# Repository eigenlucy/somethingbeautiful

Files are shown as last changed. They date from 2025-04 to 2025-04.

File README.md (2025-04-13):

# PATHFINDER

A route and activity planning bot that lives in a panel beside your door, built for the Something Beautiful Hackathon.

## Team

* [Lucy Moglia](https://eigenlucy.github.io): PCB Design, Firmware Design, Atopile Integration
* [Veronica Chambers](https://www.linkedin.com/in/victoria-cabrera-moglia/): Backend Design, LLM Integration, LLM Persistence and Memory System
* [Jessie Stiles](https://jessiestiles.github.io/portfolio1.github.io/): Enclosure CAD Design
* [Yoyo](https://exanova-y.github.io): UX Design, Pathfinding, Route Visualization

## Overview

PATHFINDER is an intelligent route planning device that helps you explore your surroundings. Tell it where you want to go, how much of a rush you're in, and what kind of activities you're looking for, and it will plan your perfect route by analyzing various databases. The system features personality-driven agents that adapt to each user's preferences over time.

### Hardware

- ESP32-S3 microcontroller
- MAX98357 I2S digital amplifier (esp-hal i2s audio library)
- ST7735S based 128 × 160 pixel LCD (st7735-lcd crate)
- WS2812B Neopixels (smart_leds crate)
- Custom PCB design (can be ordered pre-assembled)

## Atopile Hardware Architecture

The hardware is designed using [atopile](https://docs.atopile.io/latest/), a modern hardware description language that generates PCB designs. The system architecture is structured as follows:

### Components Diagram

```
┌───────────────────────────┐
│       Veramonitor         │
└───────────┬───────────────┘
            │
            ├── Power Management
            │   ├── USB-C Connector (5V)
            │   └── AMS1117-33 LDO (3.3V)
            │
            ├── Processing
            │   └── ESP32-S3 Microcontroller
            │
            ├── Input/Output
            │   ├── 6× Kailh Mechanical Switches (with RGB LEDs)
            │   ├── 1.8" TFT LCD Display (ST7735S)
            │   ├── Digital Amplifier (MAX98357) + Speaker
            │   └── MEMS Microphone (SPH0641LU4H-1)
            │
            └── Interfaces
                ├── I2C (Qwiic connector)
                ├── SPI (for LCD)
                ├── I2S (for audio)
                ├── JTAG (programming header)
                └── USB2 (for communication)
```

### Connection Diagram

The main components are connected as follows:

```
┌─────────────┐     Power (5V)     ┌────────────┐
│  USB-C Port ├───────────────────►│  AMS1117   │
└─────────────┘                    └─────┬──────┘
                                         │
                                         │ Power (3.3V)
                                         ▼
┌─────────────┐     I2C, SPI     ┌──────────────┐     GPIO     ┌─────────────┐
│  Qwiic I2C  │◄────────────────►│   ESP32-S3   ├────────────►│ Kailh Keys  │
└─────────────┘                  │              │              │ with SK6805 │
                                 │              │              │    LEDs     │
┌─────────────┐     SPI          │              │              └─────────────┘
│  1.8" LCD   │◄────────────────►│              │
└─────────────┘                  │              │
                                 │              │    I2S       ┌─────────────┐
┌─────────────┐     PDM          │              ├────────────►│   MAX98357  │
│ MEMS Mic    ├────────────────►│              │              │     Amp     │
└─────────────┘                  └──────────────┘              └──────┬──────┘
                                                                      │
                                                                      ▼
                                                               ┌─────────────┐
                                                               │   Speaker   │
                                                               └─────────────┘
```

The design files are built with atopile and can be found in `ESPHome-Panel/elec/src/`.

## Getting Started

### Prerequisites

- [atopile](https://docs.atopile.io/latest/) - For PCB design
- [rust](https://rustup.rs/), [espup](https://docs.esp-rs.org/book/installation/riscv-and-xtensa.html), [espflash](https://github.com/esp-rs/espflash) - For firmware development

See [ATO_USAGE.md](ATO_USAGE.md) for detailed instructions on working with atopile.

### Building the PCB

1. Clone the repository with submodules:
   ```
   git submodule update --init --recursive
   ```

2. Build the project:
   ```
   ato build -t all
   ```

3. Review the layout in KiCad PCB editor

4. Gerbers and PCBA files are generated through Actions runs

## References/Dependencies

* [OpenRouteService](https://openrouteservice.org/)
* [OpenRouteService Route Visualization Guide](https://medium.com/@atulvpoddar4/visualizing-routes-with-real-data-a-python-guide-to-interactive-mapping-db14189cf185)
* [Izzymonitor Project Page](https://eigenlucy.github.io/projects/izzymonitor/) and [Repo with pin refs](https://github.com/eigenlucy/ESPHome-Panel/tree/izzymonitor/)
* [Izzymonitor actions run associated with PCB on hand](https://github.com/eigenlucy/ESPHome-Panel/actions/runs/13046416119)

## Project Structure

| Directory | Description |
|---|---|
| `/` | Root directory with main README and documentation |
| `/3DModels/` | 3D model files for the enclosure (STEP files) |
| `/ESPHome-Panel/` | Hardware design files using atopile |
| `/ESPHome-Panel/elec/` | Electronic design files |
| `/ESPHome-Panel/elec/src/` | Source files for the PCB design |
| `/ESPHome-Panel/elec/layout/` | KiCad PCB layout files |
| `/ESPHome-Panel/elec/footprints/` | Custom footprints for components |
| `/ESPHome-Panel/build/` | Build outputs including BOM, gerbers, etc. |
| `/RustFirmwareWorking/` | Firmware source code in Rust |
| `/RustFirmwareWorking/izzymonitor-firmware/` | Current firmware implementation |
| `/RustFirmwareWorking/izzymonitor-firmware/src/` | Rust source code for firmware |
| `/RustFirmwareWorking/izzymonitor-firmwareWorkingBak/` | Backup of working firmware |

## Project Status and To-Do List

### PCB/Basic Firmware
- [x] PCB works
- [x] Initial atopile setup
- [x] Get Ato build working with V3 compiler
- [ ] Board recording sound from PDM I2S microphone
- [ ] ST7735 LCD display working over SPI
- [ ] I2S amp/speaker working 
- [x] Buttons/WS2812B LEDs working

### Enclosure
- [x] Design 3D-printable wall-mountable enclosure with personality
- [x] Accommodate all components (buttons, microphone, speakers, USB ports)

### Firmware/UI
- [ ] UI/Menu design
- [ ] LCD text based UI and voice animations
- [ ] Web server integration to send and receive audio and text
- [ ] Button-based UI for user selection, mode settings, and volume control
- [ ] Route feedback convo mode

### LLM Integration
- [ ] User recognition with personalized agents
- [x] Route planning integration (OpenRouteService)
- [ ] Voice synthesis and speech recognition
- [x] Agent personality development
- [ ] Gradual Infilatration of Fixations to Pathfinding :3

### Backend
- [ ] Request processing from device
- [x] Speech-to-text integration
- [ ] Audio and text file sharing from web server
- [x] Agent persistence and memory system for user preferences
- [x] Map / location lookup system

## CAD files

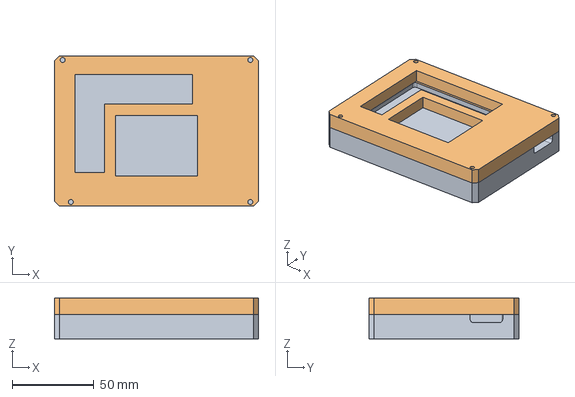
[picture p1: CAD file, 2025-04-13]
3DModels/HAassembly.step
125.0 x 92.0 x 25.0 mm
lid

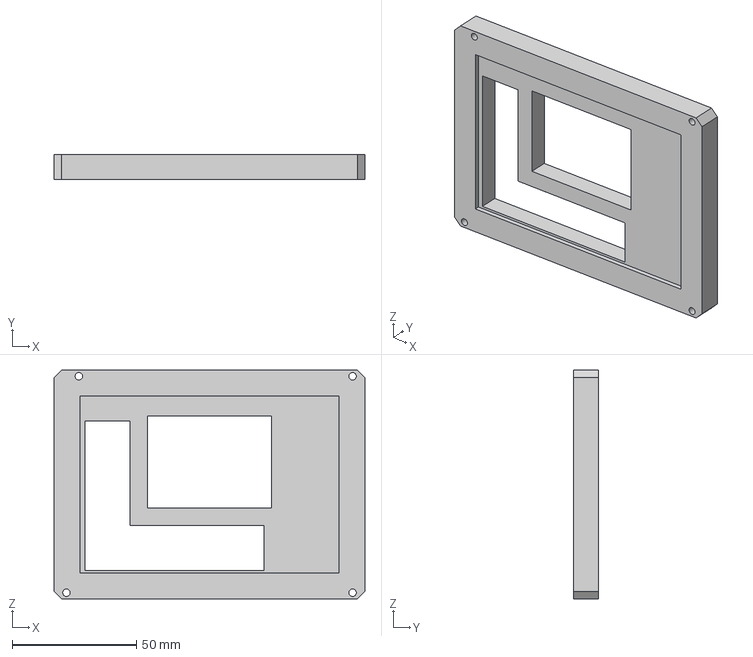
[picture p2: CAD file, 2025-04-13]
3DModels/lid v4.step
125.0 x 10.0 x 92.0 mm

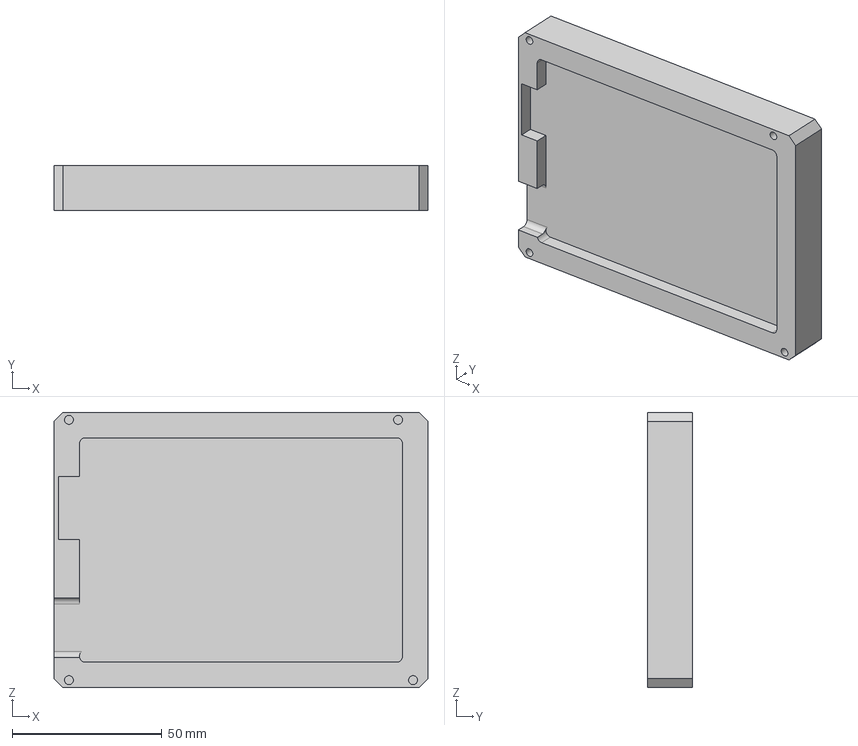
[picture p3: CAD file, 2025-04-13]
3DModels/HAbase.step
125.0 x 15.0 x 92.0 mm

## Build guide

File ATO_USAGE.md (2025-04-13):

# Atopile Usage 101
See [atopile docs](https://docs.atopile.io/atopile/introduction) for detailed guides on usage. Install instructions below

## Building the project
### 1: Clone the required submodules
```$ git submodule update --init --recursive```
- You actually wanna make sure you are using the specific commit hash we built this around for the ESPHome-Panel
### 2: Build the project to select components based on JLCPCB availability and load them into the kicad PCB
``` $ ato build -t all```
### 3: Complete/review the layout with Kicad Standalone PCB editor
### 4: Gerbers/PCBA files are generated through an Actions run on a commit and placed in the build artifacts folder

## Linux Install (should work with Ubuntu, Debian, Arch, and NixOS)
### 1: Install [uv](https://github.com/astral-sh/uv)
### 2: Install kicad with your preferred package manager (apt for debian, pacman for arch, etc)
### 3: Install atopile as a tool with uv. As of writing this, you should be using python 3.13.2 
```$ uv tool install atopile```
#### 3.1: (alternative install, my preferred method, easier to debug and manage versions):
#### 3.2: clone the main [atopile repo](https://github.com/atopile/atopile)
#### 3.3: remove the uv lock file
```$ rm uv.lock```
#### 3.4: sync repo to dev release
```$ uv sync --dev```
#### 3.5: compile atopile
```$ uv build```
#### 3.6: install the binary
```$ uv tool install atopile-0.3.XX-cp313-cp313-linux-_x86_64.whl```
#### 3.7: Add the uv tools binary directory to your PATH (command depends on your shell, eg with fish)
```$ fish_add_path /home/user/.local/share/uv/tools/atopile/```
### 4: Check your version with 
```$ ato --version```
### 5: configure the atopile plugin 
```$ ato configure```

## Mac Install
### 1: Install [Homebrew](https://brew.sh/)
### 2: Install [kicad 9](https://formulae.brew.sh/cask/kicad)
### 3: install atopile with Homebrew 
```$ brew install atopile/tap/atopile```
### 4: configure the atopile plugin 
```$ ato configure```

## Visual Studio Code/Cursor Extension Install
Install the [atopile extension](https://marketplace.visualstudio.com/items?itemName=atopile.atopile) into Cursor or VSC

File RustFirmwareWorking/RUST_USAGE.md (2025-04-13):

# Refs/Deps:
- Install the Rust toolchain with [RustUp](https://rustup.rs/)
- Install [espup](https://docs.esp-rs.org/book/installation/riscv-and-xtensa.html)
- Install [espflash](https://docs.esp-rs.org/book/tooling/espflash.html)
- [Rust On ESP-IDF Template](https://github.com/esp-rs/esp-idf-template)

# Libraries:
- [LCD Library](https://crates.io/crates/st7735-lcd), see [Repo](https://github.com/sajattack/st7735-lcd-rs) with docs
- [SmartLeds](https://docs.rs/smart-leds/latest/smart_leds/), for the neopixels
- [ESP32 I2S Audio Library](https://docs.rs/esp32-hal/latest/esp32_hal/i2s/index.html), handles the audio from the microphone and to the speaker

# Flashing
- Install prereqs ```$ cargo generate esp-rs/esp-idf-template cargo```
- ```$ cargo build```
- ```$ cargo run --release```

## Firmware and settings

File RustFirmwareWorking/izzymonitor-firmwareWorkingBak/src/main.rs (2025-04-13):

//! Main entry point for VeraMonitor
//! ESP32-S3 based wall-mounted LLM-integrated Google Maps assistant

#![no_std]
#![no_main]
#![feature(type_alias_impl_trait)]

use esp_backtrace as _;
use esp_hal::{
    clock::{ClockControl, CpuClock},
    gpio::{AnyPin, Gpio0, Gpio10, Gpio11, Gpio12, Gpio13, Gpio14, Gpio16, Gpio21, Gpio35, Gpio45, Gpio46, Gpio47, Gpio48, Gpio9, GpioPin, Input, Output, PullUp, PushPull},
    prelude::*,
    rmt::{PulseCode, Rmt, TxChannel, TxChannelConfig},
    peripherals::Peripherals,
    spi::master::{Spi, SpiBus},
    timer::TimerGroup,
    IO,
};
use embassy_executor::Spawner;
use embassy_time::{Duration, Timer};
use esp_println::println;
use heapless::Vec;

mod display;
mod buttons;
mod led;

use display::ButtonLayout;
use buttons::{Button, BUTTON_STATES};
use led::{LedController, colors, RgbColor};

// Number of LEDs in the strip
const LED_COUNT: usize = 6;

// RMT buffer size (each LED needs 24 bits × 2 pulses per bit + reset pulse)
const RMT_BUFFER_SIZE: usize = LED_COUNT * 24 * 2 + 1;

// Define the menu system
enum MenuScreen {
    Startup,
    Main,
    Trip,
    Settings,
}

// Define button labels for different screens
const MAIN_BUTTONS: [&str; 6] = ["Menu", "Trip", "Set", "Mic", "Up", "Down"];
const TRIP_BUTTONS: [&str; 6] = ["Back", "New", "View", "Map", "Up", "Down"];
const SETTINGS_BUTTONS: [&str; 6] = ["Back", "WiFi", "LED", "User", "Up", "Down"];

// Task for display management
#[embassy_executor::task]
async fn display_task(
    mut lcd: display::Display,
    active_button: &'static core::cell::Cell<usize>,
) {
    // Start with the startup screen
    let mut current_screen = MenuScreen::Startup;
    lcd.draw_startup().unwrap();
    
    // Wait a moment on the startup screen
    Timer::after(Duration::from_millis(2000)).await;
    
    // Switch to main screen
    current_screen = MenuScreen::Main;
    let mut layout = ButtonLayout {
        labels: MAIN_BUTTONS,
        active_index: 0,
    };
    
    lcd.draw_main_screen(&layout).unwrap();
    
    loop {
        // Get the currently active button
        let current_button = active_button.get();
        
        // Update the active button in the layout if it changed
        if current_button != layout.active_index {
            layout.active_index = current_button;
            
            // Redraw based on current screen
            match current_screen {
                MenuScreen::Startup => {
                    // Shouldn't get here, but just in case
                    lcd.draw_startup().unwrap();
                },
                MenuScreen::Main => {
                    layout.labels = MAIN_BUTTONS;
                    lcd.draw_main_screen(&layout).unwrap();
                },
                MenuScreen::Trip => {
                    layout.labels = TRIP_BUTTONS;
                    lcd.draw_title("Trip Planner").unwrap();
                    lcd.draw_buttons(&layout).unwrap();
                },
                MenuScreen::Settings => {
                    layout.labels = SETTINGS_BUTTONS;
                    lcd.draw_title("Settings").unwrap();
                    lcd.draw_buttons(&layout).unwrap();
                },
            }
        }
        
        // Check for screen transitions based on button presses
        for (i, state) in BUTTON_STATES.iter().enumerate() {
            let button_state = critical_section::with(state, |s| {
                *s.borrow()
            });
            
            if button_state == buttons::ButtonState::Pressed {
                match (current_screen, i) {
                    // From main screen
                    (MenuScreen::Main, 0) => {}, // Menu button does nothing on main screen
                    (MenuScreen::Main, 1) => {
                        // Trip button - go to trip screen
                        current_screen = MenuScreen::Trip;
                        layout.labels = TRIP_BUTTONS;
                        layout.active_index = 0;
                        lcd.clear().unwrap();
                        lcd.draw_title("Trip Planner").unwrap();
                        lcd.draw_box(5, 25, display::SCREEN_WIDTH - 10, display::SCREEN_HEIGHT - 60).unwrap();
                        lcd.draw_text("No trips scheduled", 20, 50, display::COLOR_TEXT, false).unwrap();
                        lcd.draw_buttons(&layout).unwrap();
                    },
                    (MenuScreen::Main, 2) => {
                        // Settings button - go to settings screen
                        current_screen = MenuScreen::Settings;
                        layout.labels = SETTINGS_BUTTONS;
                        layout.active_index = 0;
                        lcd.clear().unwrap();
                        lcd.draw_title("Settings").unwrap();
                        lcd.draw_box(5, 25, display::SCREEN_WIDTH - 10, display::SCREEN_HEIGHT - 60).unwrap();
                        lcd.draw_text("WiFi: Not Connected", 10, 40, display::COLOR_TEXT, false).unwrap();
                        lcd.draw_text("LED: Medium", 10, 55, display::COLOR_TEXT, false).unwrap();
                        lcd.draw_text("User: Guest", 10, 70, display::COLOR_TEXT, false).unwrap();
                        lcd.draw_buttons(&layout).unwrap();
                    },
                    
                    // From trip screen
                    (MenuScreen::Trip, 0) => {
                        // Back button - go to main screen
                        current_screen = MenuScreen::Main;
                        layout.labels = MAIN_BUTTONS;
                        layout.active_index = 0;
                        lcd.draw_main_screen(&layout).unwrap();
                    },
                    
                    // From settings screen
                    (MenuScreen::Settings, 0) => {
                        // Back button - go to main screen
                        current_screen = MenuScreen::Main;
                        layout.labels = MAIN_BUTTONS;
                        layout.active_index = 0;
                        lcd.draw_main_screen(&layout).unwrap();
                    },
                    
                    // Default - ignore other button presses
                    _ => {},
                }
                
                // Break after handling a button press
                break;
            }
        }
        
        // Short delay to prevent excessive CPU usage
        Timer::after(Duration::from_millis(50)).await;
    }
}

// Main function
#[embassy_executor::main]
async fn main(spawner: Spawner) {
    // Initialize the ESP32
    println!("Starting VeraMonitor...");
    let peripherals = Peripherals::take();
    
    // Configure clocks
    let system = peripherals.SYSTEM.split();
    let clocks = ClockControl::configure(system.clock_control, CpuClock::Clock240MHz).freeze();
    
    // Configure I/O
    let io = IO::new(peripherals.GPIO, peripherals.IO_MUX);
    
    // Initialize the timer
    let timer_group0 = TimerGroup::new(peripherals.TIMG0, &clocks);
    embassy_time::time_driver_embassy_time_timg0::schedule_timer(timer_group0);
    
    // Configure LED backlight for display
    let mut backlight = io.pins.gpio46.into_push_pull_output();
    backlight.set_high().unwrap();
    
    // Configure the SPI interface for the display
    let spi = peripherals.SPI2;
    let sclk = io.pins.gpio12;
    let mosi = io.pins.gpio13;
    let cs = io.pins.gpio11;
    
    // Configure DC and RST pins
    let dc = io.pins.gpio10.into_push_pull_output();
    let rst = io.pins.gpio9.into_push_pull_output();
    
    // Configure SPI
    let spi_config = esp_hal::spi::master::Config::new()
        .baudrate(27.MHz().into())
        .bit_order(esp_hal::spi::master::BitOrder::MsbFirst)
        .data_mode(esp_hal::spi::master::Mode::Mode0);
    
    let spi = Spi::new(
        spi,
        sclk,
        mosi,
        Option::<esp_hal::gpio::AnyPin>::None, // No MISO needed
        Option::<esp_hal::gpio::AnyPin>::None, // Manual CS handling
        &spi_config,
    ).unwrap();
    
    // Initialize the display
    println!("Initializing display...");
    let lcd = match display::Display::new(spi, dc, rst) {
        Ok(display) => {
            println!("Display initialized!");
            display
        },
        Err(e) => {
            println!("Display initialization failed: {}", e);
            panic!();
        }
    };
    
    // Configure the RMT for WS2812B LEDs
    println!("Initializing LEDs...");
    let rmt = Rmt::new(peripherals.RMT, 80.MHz(), &clocks).unwrap();
    let led_pin = io.pins.gpio16.into_push_pull_output();
    
    let mut rmt_buffer = [PulseCode::default(); RMT_BUFFER_SIZE];
    
    let tx_config = TxChannelConfig::new().clock_divider(1);
    let tx_channel = rmt.channel0.configure(led_pin, tx_config).unwrap();
    
    let led_controller = LedController::new(tx_channel, &mut rmt_buffer, LED_COUNT);
    
    // Configure buttons
    println!("Initializing buttons...");
    let button1 = Button::new(
        io.pins.gpio14.into_pull_up_input(),
        "Button 1",
        0,
        &BUTTON_STATES[0],
    );
    
    let button2 = Button::new(
        io.pins.gpio21.into_pull_up_input(),
        "Button 2",
        1,
        &BUTTON_STATES[1],
    );
    
    let button3 = Button::new(
        io.pins.gpio47.into_pull_up_input(),
        "Button 3",
        2,
        &BUTTON_STATES[2],
    );
    
    let button4 = Button::new(
        io.pins.gpio48.into_pull_up_input(),
        "Button 4",
        3,
        &BUTTON_STATES[3],
    );
    
    let button5 = Button::new(
        io.pins.gpio45.into_pull_up_input(),
        "Button 5",
        4,
        &BUTTON_STATES[4],
    );
    
    let button6 = Button::new(
        io.pins.gpio35.into_pull_up_input(),
        "Button 6",
        5,
        &BUTTON_STATES[5],
    );
    
    // Active button index (shared between tasks)
    static ACTIVE_BUTTON: core::cell::Cell<usize> = core::cell::Cell::new(0);
    
    // Spawn tasks
    println!("Spawning tasks...");
    
    // Button monitoring tasks
    spawner.spawn(buttons::button_task(button1)).ok();
    spawner.spawn(buttons::button_task(button2)).ok();
    spawner.spawn(buttons::button_task(button3)).ok();
    spawner.spawn(buttons::button_task(button4)).ok();
    spawner.spawn(buttons::button_task(button5)).ok();
    spawner.spawn(buttons::button_task(button6)).ok();
    
    // LED animation task
    spawner.spawn(led::led_animation_task(led_controller, &BUTTON_STATES)).ok();
    
    // Display task
    spawner.spawn(display_task(lcd, &ACTIVE_BUTTON)).ok();
    
    // Main loop - update active button based on button states
    println!("Entering main loop...");
    loop {
        for (i, state) in BUTTON_STATES.iter().enumerate() {
            let button_state = critical_section::with(state, |s| {
                *s.borrow()
            });
            
            if button_state == buttons::ButtonState::Pressed {
                ACTIVE_BUTTON.set(i);
                break;
            }
        }
        
        // Short delay
        Timer::after(Duration::from_millis(50)).await;
    }
}

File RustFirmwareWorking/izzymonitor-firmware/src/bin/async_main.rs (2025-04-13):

#![no_std]
#![no_main]

use embassy_executor::Spawner;
use embassy_time::{Duration, Timer};
use esp_backtrace as _;
use esp_hal::clock::CpuClock;
use esp_hal::gpio::{Pull, Level, Input, Output};
use esp_hal::spi::{Spi, SpiMode};
use esp_hal::prelude::*;
use log::{debug, info, error};
use ws2812_esp32_rmt_driver::driver::color::LedPixelColorGrb24;
use ws2812_esp32_rmt_driver::{LedPixelEsp32Rmt, RGB8_BRIGHTNESS_CHANNEL_FACTOR};
use st7735_lcd::{ST7735, Orientation};
use embedded_graphics::{
    mono_font::{ascii::FONT_6X10, MonoTextStyleBuilder},
    pixelcolor::Rgb565,
    prelude::*,
    primitives::{Rectangle, PrimitiveStyle},
    text::{Baseline, Text},
};
use smart_leds::{
    brightness, gamma,
    hsv::{hsv2rgb, Hsv},
    SmartLedsWrite,
    RGB8,
};

extern crate alloc;

/*
#[embassy_executor::task]
 async fn blink_backlight(mut backlight_pin: Output<'static>) {
    loop {
        Timer::after(Duration::from_secs(1)).await;
        info!("Hello world!");
        backlight_pin.toggle();
    }
}
*/

async fn key_watcher(mut key_pin: Input<'static>, key_name: &'static str) {
    loop {
        let mut del_var = 2000;

        key_pin.wait_for_falling_edge().await;
        info!("pressed {key_name}");
        del_var = del_var - 300;
        // If updated delay value drops below 300 then reset it back to starting value
        if del_var < 500 {
            del_var = 2000;
        }
        info!("surpassed delay value");
        // Pub
    }
}

#[embassy_executor::task]
async fn watch_key(key_pin: Input<'static>, key_name: &'static str) {
    key_watcher(key_pin, key_name).await
}

#[embassy_executor::task]
async fn watch_key2(key_pin: Input<'static>, key_name: &'static str) {
    key_watcher(key_pin, key_name).await
}

#[embassy_executor::task]
async fn watch_key3(key_pin: Input<'static>, key_name: &'static str) {
    key_watcher(key_pin, key_name).await
}

#[embassy_executor::task]
async fn watch_key4(key_pin: Input<'static>, key_name: &'static str) {
    key_watcher(key_pin, key_name).await
}

#[embassy_executor::task]
async fn watch_key5(key_pin: Input<'static>, key_name: &'static str) {
    key_watcher(key_pin, key_name).await
}

#[embassy_executor::task]
async fn watch_key6(key_pin: Input<'static>, key_name: &'static str) {
    key_watcher(key_pin, key_name).await
}

#[esp_hal_embassy::main]
async fn main(spawner: Spawner) -> Result<(), esp_hal::rmt::Error> {
    // generator version: 0.2.2

    let config = esp_hal::Config::default().with_cpu_clock(CpuClock::max());
    let peripherals = esp_hal::init(config);

    esp_alloc::heap_allocator!(72 * 1024);

    esp_println::logger::init_logger_from_env();

    let timer0 = esp_hal::timer::systimer::SystemTimer::new(peripherals.SYSTIMER);
    esp_hal_embassy::init(timer0.alarm0);

    info!("Embassy initialized!");

    let timer1 = esp_hal::timer::timg::TimerGroup::new(peripherals.TIMG0);
    info!("initing wifi??");
    let _init = esp_wifi::init(
        timer1.timer0,
        esp_hal::rng::Rng::new(peripherals.RNG),
        peripherals.RADIO_CLK,
    )
    .unwrap();
    info!("inited wifi??");

    let mut backlight = Output::new(peripherals.GPIO46, Level::Low);
    backlight.set_high();
    
    // Initialize the ST7735 display
    info!("Initializing ST7735 display");
    
    // Define the pins for the ST7735 display
    let sck = peripherals.GPIO36;
    let mosi = peripherals.GPIO37;
    let cs = peripherals.GPIO38;
    let dc = Output::new(peripherals.GPIO39, Level::Low);
    let rst = Output::new(peripherals.GPIO40, Level::Low);
    
    // Configure SPI for the display
    let spi = Spi::new_txonly(
        peripherals.SPI2,
        sck,
        mosi,
        cs,
        27u32.MHz(),
        SpiMode::Mode0,
        &esp_hal::clock::CpuClock::get()
    );
    
    // Initialize the ST7735 driver
    let mut display = ST7735::new(spi, dc, rst, true, false, 160, 128);
    
    // Initialize the display
    display.init(&mut |delay_ms| {
        Timer::after(Duration::from_millis(delay_ms as u64)).await;
    }).unwrap();
    display.set_orientation(&Orientation::Landscape).unwrap();
    display.clear(Rgb565::BLACK.into()).unwrap();
    
    // Draw a welcome message
    let text_style = MonoTextStyleBuilder::new()
        .font(&FONT_6X10)
        .text_color(Rgb565::GREEN)
        .build();
    
    let border_style = PrimitiveStyle::with_stroke(Rgb565::YELLOW, 1);
    
    // Draw a border around the display
    Rectangle::new(Point::new(0, 0), Size::new(160, 128))
        .into_styled(border_style)
        .draw(&mut display)
        .unwrap();
    
    // Draw welcome text
    Text::with_baseline("IzzyMonitor Ready!", Point::new(20, 20), text_style, Baseline::Top)
        .draw(&mut display)
        .unwrap();
    
    info!("ST7735 display initialized");
    
    // Initialize the Delay peripheral, and use it to toggle the LED state in a
    // loop.
    //

    let led_pin = peripherals.GPIO16;
    info!("creating LED driver");
    const LED_COUNT: usize = 6;
    let mut led = LedPixelEsp32Rmt::<RGB8, LedPixelColorGrb24, _>::new(0, led_pin)?;
    info!("created LED driver");
    let mut color = Hsv {
        hue: 0,
        sat: 255,
        val: 255,
    };

    let mut data: [RGB8; LED_COUNT] = [(0, 0, 0).into(); LED_COUNT];

    /*
    //let _ = spawner;
    let res = spawner.spawn(blink_backlight(backlight));
    match res {
        Ok(_) => info!("spawned backlight blinker"),
        Err(error) => error!("Error spawning task: {error}"),
    }
    */

    let key1 = Input::new(peripherals.GPIO14, Pull::Up);
    let res = spawner.spawn(watch_key(key1, "key 1"));
    match res {
        Ok(_) => info!("spawned key 1"),
        Err(error) => error!("Error spawning task: {error}"),
    }

    let key2 = Input::new(peripherals.GPIO21, Pull::Up);
    let res = spawner.spawn(watch_key2(key2, "key 2"));
    match res {
        Ok(_) => info!("spawned key 2"),
        Err(error) => error!("Error spawning task: {error}"),
    }

    let key3 = Input::new(peripherals.GPIO47, Pull::Up);
    let res = spawner.spawn(watch_key3(key3, "key 3"));
    match res {
        Ok(_) => info!("spawned key 3"),
        Err(error) => error!("Error spawning task: {error}"),
    }

    let key4 = Input::new(peripherals.GPIO48, Pull::Up);
    let res = spawner.spawn(watch_key4(key4, "key 4"));
    match res {
        Ok(_) => info!("spawned key 4"),
        Err(error) => error!("Error spawning task: {error}"),
    }

    let key5 = Input::new(peripherals.GPIO45, Pull::Up);
    let res = spawner.spawn(watch_key5(key5, "key 5"));
    match res {
        Ok(_) => info!("spawned key 5"),
        Err(error) => error!("Error spawning task: {error}"),
    }

    let key6 = Input::new(peripherals.GPIO35, Pull::Up);
    let res = spawner.spawn(watch_key6(key6, "key 6"));
    match res {
        Ok(_) => info!("spawned key 6"),
        Err(error) => error!("Error spawning task: {error}"),
    }
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
